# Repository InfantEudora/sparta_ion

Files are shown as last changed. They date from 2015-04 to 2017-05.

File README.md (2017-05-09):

Open Source Sparta ION
=============
There's a bunch of (Dutch) blog posts that go with this: (http://infant.tweakblogs.net/blog/cat/2875)

This repository contains the following:

 folder       |  descr
--------------|-------------------------------------------------------------
 eagle        | All relevant eagle files, BOM lists.
 ion_firmware | AVR Studio projects for the different kinds of firmware.
 ion_software | Software for testing, or uploading hex files.
 lib          | Files used in either firmware or software.
 lib_ion      | Files used for Sparta ION specific code.

All files in this repository are released under GNU GPLv3 (https://www.gnu.org/copyleft/gpl.html)

Software used:
----------------
 - Atmel Studio 6.1.2440 - BETA (http://www.atmel.com/microsite/atmel_studio6/)
 - GCC 4.9.2
 - Windows: Cygwin(https://cygwin.com/install.html)
 - Eagle 6.1.0 (http://www.cadsoftusa.com/)

Firmware:
----------------

The firmware running your bike's motor, consists of three parts:
 - A bootloader, started on powerup.
 - The actual firmware, called application executed by the bootloader.
 - Configuration memory, stored in ROM.

The bootloader uses two blocks to identify the harware it's running on, and what firmware should be loaded.
The firware uses one block to read/write settings, which are currently the strain gauge calibration.

If you wan't to build a control PCB, use the latest revision of 3phasecntrl.

New Hardare Revision Wishlist:
 - Crystal
 - ESD protection on HALL input. (REV2)

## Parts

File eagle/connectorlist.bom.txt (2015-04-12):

CONNECTOR LIST:

Display:
TE CONNECTIVITY / AMP  1445022-3 HOUSING, RECEPTACLE, SINGLE ROW, 3WAY
1111082

TE CONNECTIVITY / AMP  794610-1  CONTACT SOCKET, 24-20AWG, CRIMP
1111151

TE CONNECTIVITY / AMP  0-1445049-3  CONNECTOR HOUSING, PLUG, 3 WAY, NYLON
1111098

TE CONNECTIVITY / AMP  1-794612-0  CONTACT PIN, 20-24AWG
1111149

Motor:
TE CONNECTIVITY / AMP  282105-1  TAB HOUSING, 3WAY
150678

TE CONNECTIVITY / AMP  282087-1  SOCKET HOUSING, 3WAY
150423

TE CONNECTIVITY / AMP  183025-1.  CRIMP SOCKET, 18-15AWG
151075

TE CONNECTIVITY / AMP  183024-1  CRIMP PIN, TAB, 20-15AWG
151040

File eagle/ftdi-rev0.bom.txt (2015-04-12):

Partlist exported from E:/IDE-E/Mijn Documenten/Projects/code/sparta_ion.git/eagle/ftdi.sch at 4/8/2015 5:38:11 PM

Assembly variant: 

Qty Value        Device            Parts             Farnell FarnellAlt1
1                ADAFRUIT_USBMINIB USB                                  
2                JP1E              XIN, XOUT                            
2                MA03-1            X1, X2                               
2                MA04-1            SV1, SV2                             
1                SJ                SJ1                                  
1                SJ2W              SJ2                                  
4   1k           R-EU_M0805        R3, R30, R32, R35 2078954            
1   2R2          R-EU_M0805        F1                2078937            
1   4.7u/16V     C-EUC0805K        C1                1759427            
1   4k7          R-EU_M0805        R2                2074469            
2   10R          R-EU_M0805        R31, R36          2073604            
1   100k         R-EU_M0805        R34               2073608            
3   100n         C-EUC0805K        C2, C3, C45       2320839            
1   390k         R-EU_M0805        R33               9234322            
3   470R         R-EU_M0805        R1, R8, R67       2073777            
3   BC847        BC847             T1, T5, T6        1081232            
1   EL3H7(TA)-VG TLP283            OK1                                  
1   FT232RL      FT232RL           IC1               1146032            
1   GREEN        LEDCHIPLED_0805   TX                2290331            
1   RED          LEDCHIPLED_0805   RX                1318244            
1   SN65HVD1780  SN75176BD         U1

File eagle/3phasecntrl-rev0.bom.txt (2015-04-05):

Partlist exported from E:/IDE-E/Mijn Documenten/Projects/code/sparta_ion.git/eagle/3phasecntrl-rev0.sch at 4/5/2015 2:22:53 PM

Assembly variant: 

Qty Value              Device             Parts                              Farnell FarnellAlt1
1                      MA03-1             STRAIN                                                
1                      MA05-1             X3-HALL                                               
2                      MA07-1             MMUP, PWM                          1516283            
1                      SJ2W               VBUS                                                  
7   1k                 R-EU_M0805         R10, R12, R30, R35, R45, R67, R68  2078954            
1   2R2                R-EU_M0805         R58                                2078937            
1   4.7u/16V           C-EUC0805K         C16                                1759427            
4   4k7                R-EU_M0805         R8, R13, R14, R32                  2074469            
8   10R                R-EU_M0805         R3, R4, R5, R6, R7, R9, R11, R31   2073604            
2   10u/16V            CPOL-EU153CLV-0405 C4, C11                            9265554 9696920    
1   10u/50V            CPOL-EU153CLV-0605 C6                                 2068686            
1   68u/25V            CPOL-EU153CLV-0605 C5                                 2326209            
3   100k               R-EU_M0805         R1, R27, R34                       2073608            
8   100n               C-EUC0805K         C1, C2, C3, C7, C14, C15, C19, C20 2320839            
1   140mA              PTCFUSE-1812       F1                                 1345923            
1   150u/250mA         L-USWE-TPC         L1                                 2328764            
1   240k               R-EU_M0805         R29                                2139055            
3   390k               R-EU_M0805         R26, R28, R33                      9234322            
4   470R               R-EU_M0805         R2, R18, R21, R22                  2073777            
1   ATXmega32A4U       XMEGA16A4A         IC3                                2443192            
1   BAT46WH            DIODE-SOD323-W     D5                                 2069340            
2   BC847              BC847              T1, T2                             1081232            
1   GREEN              LEDCHIPLED_0805    LED1                               2290331            
1   LD1117S33          LM340ST-ST         IC6                                1467779            
1   LD1117S50          LM340ST-ST         IC4                                1467780            
1   LM5008MM           LM5008MM           U1                                 2112610            
3   MOUNT-PAD-ROUND3.2 MOUNT-PAD-ROUND3.2 H1, H2, H3                                            
1   PROG-ATMEL-PDI     PROG-ATMEL-PDI     XP                                                    
1   RED                LEDCHIPLED_0805    LED2                               1318244            
1   SM6T39A            DIODE-SMB          D4                                 9802703            
1   SS110B             DIODE-SMB          D1                                 1861422

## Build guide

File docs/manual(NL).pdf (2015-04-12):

## Aansluiten:

(REV0 en REV1)

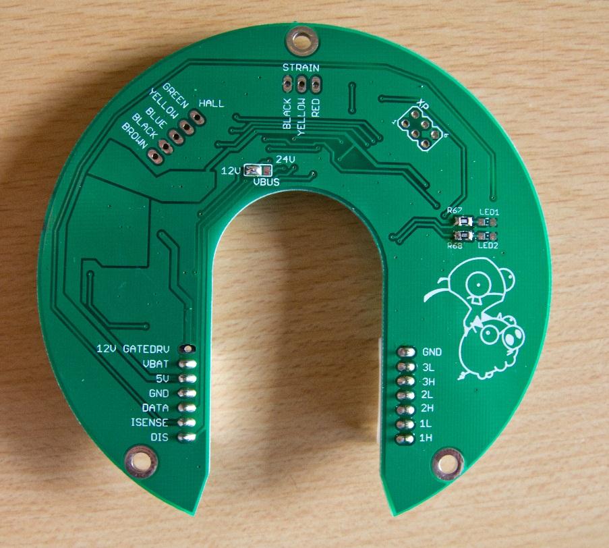
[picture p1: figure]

De vervanging voor het originele Sparta control PCB, kan los getest worden, zonder dat hij eerst ingebouwd hoeft te worden en het is ook niet nodig hem op de drive PCB aan te sluiten.

De GND en VBAT aansluiting op de linker connector hierboven. Het PCB heeft 6.5V nodig om op te starten, en in het geval van een 12V bus zoals hierboven, 10V om goed met het display te communiceren. Het hele PCB is ompool beveiligd. (De drive PCB echter niet.)

Nadat het PCB aan staat, gaat heel even het rode led alleen aan. Hier bevind het PCB zich in bootload mode. Binnen 1 seconde wordt de firmware uitgevoerd, en gaat het groene led knipperen.

Als het display niet aangesloten is, licht het rode led op, het groene led blijft door knipperen. Zodra het display aangesloten is, knippert alleen het groene led nog.

Het display heeft 5V nodig, de GND is aan de batterij min gekoppeld. De 5V mag van dit PCB komen, of een externe.

De connector uit het ronde display heeft een wit, geel en rood of oranje draad:

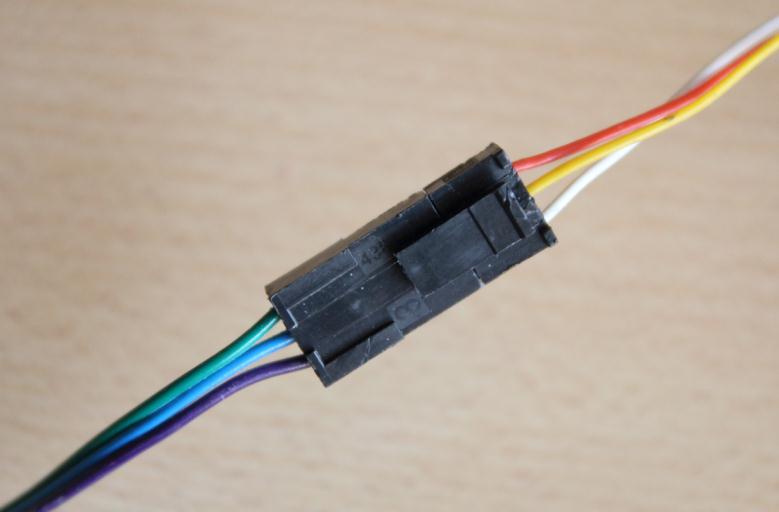
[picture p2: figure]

De male connector die oorspronkelijk uit de accu komt kan gebruikt worden, de kleur codering staat ook in het eagle schema:

Display Connector (Female) | Accu Connector (Male) | Signaal
Rood | Groen | 5V
Geel | Blauw | DATA
Wit | Paars | GND

Als je de display draad door de as naar buiten wilt brengen, is het handig om die op de linker connector punten te solderen.

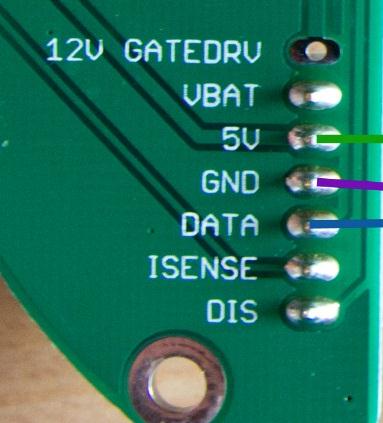
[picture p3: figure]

Bij het losmaken van het orgineel is het handig eerst de hall sensor draden los te solderen, vervolgens het PCB lost schroeven en de twee connectoren los maken. Als laatste te trapas sensor draden los maken.

Let bij het terugzetten er weer op dat de trapas sensor vanaf de onderzijde van het PCB gaat, en de hall sensoren via de bovenkant:

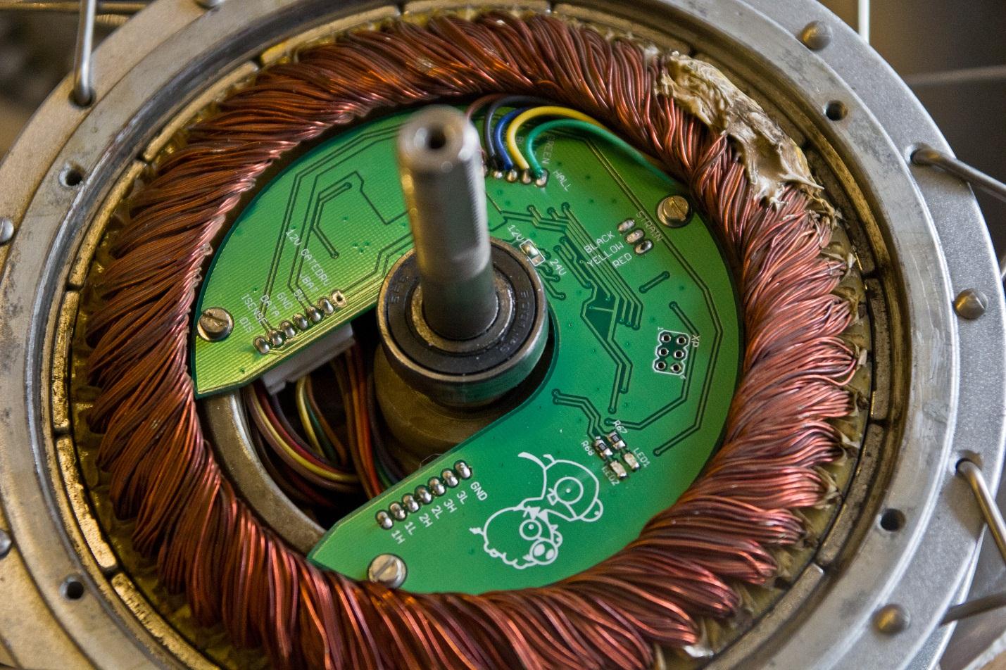
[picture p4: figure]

De connector die oorspronkelijk uit de accu naar de motor loopt, wordt geschakeld: de plus van de accu zit niet permanent aan de motor verbonden.

Het is op het moment nodig, en gezien de kans groot is dat jouw accu PCB niet meer werkt, de accu plus en min direct op de motor te zetten:

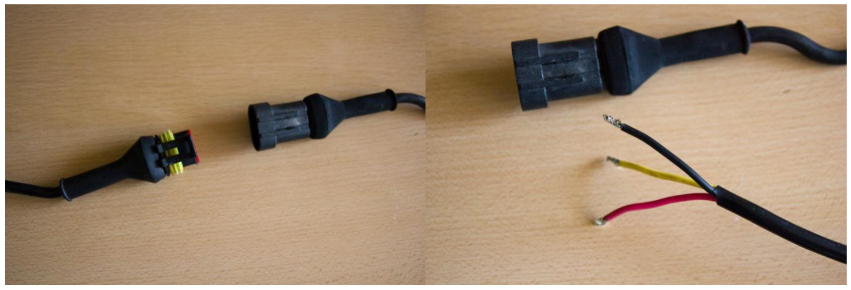
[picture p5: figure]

De kleurcodering hier is:

Accu Min | Zwart
Data | Geel
Accu Plus | Rood
Er is geen enkele reden dat de data draad zo dik moet zijn. Er gaat hoogstens een paar mA door heen.

De spannings-rating van de componenten die aan de accu hangen zijn 50V. Dit control PCB heeft een ingangs TVS diode die c.a. 39V gaat geleiden. De overspanning staat in de firmware rond de 38V, als deze spanning gemeten wordt, slaat de trapondersteuning af.

De onderspanning zit op 18V. Rond de 19V wordt het vermogen terug geregeld.

Normaliter is de accu rond de 28V als hij vol is, en 20V als hij leeg is.

## Display:

Op het moment van schrijven zijn een aantal van de originele features weg:
- Accu percentage. (Gezien dit toch gegarandeerd een keer de mist in gaat.)
- Afgelegde afstand.
- Aansturen van verlichting. (Dit zit in de accu, maar dient via het display aangezet te worden.)

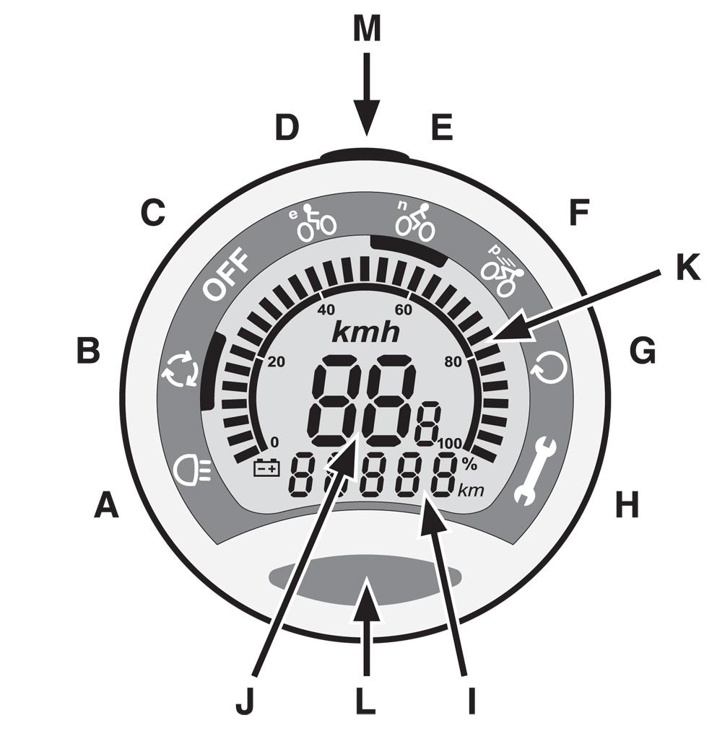
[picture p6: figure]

In normale toestand toont het scherm de snelheid op [J]. De stroom uit de accu (positief of negatief bij terug leveren) op [I]. [K] geeft het throttle signaal of trapkracht aan, van 0-100. De hoogste van de twee wordt getoond.

Met de middelste knop gaat de trapondersteuning aan, er zijn 5 standen. Elke stand regelt naar 3 Ampere * percentage throttle. Als het wiel van de grond is, betekend dit dat in elke stand met elke hoeveelheid throttle uiteindelijk het wiel op maximum snelheid gaat draaien.

De bovenste knop ingedrukt houden, en daarna de middelste schakelt de display verlichting aan/uit.

De bovenste knop (M) navigeert nu door verschillende menu’s heen, met de knop aan de voorkant selecteer je opties en stel je waardes in.

Menu F1:

- 0: [J] toont snelheid.
- 1: [J] toont accu spanning.
- 2: [J] toont trapsensor waarde. (Rond de 500).
- 3: Minimum trapsensor waarde.
- 4: Maximum trapsensor waarde.
- 5: 6-fase PWM waarde.

Menu F2:

Stelt de PWM limiet in. Standaard staat deze op 9. Dit beïnvloed de topsnelheid, maar ook de maximum kracht. Op stand 0 zul je merken dat hij vrijwel altijd tegen werkt, en er stroom de accu in loopt.

Menu F3:

Calibratie voor trapas sensor. De middelste knop ingedrukt houden gaat de waarde mee omhoog zolang het hudige signaal op de sensor grooter is dan de calibratie waarde. Als je de bovenste knop langer dan c.a. 5 sec. ingedrukt houd, reset de waarde en kom je in menu F3 terecht.

Menu F4:

Als deze op waarde 4 gezet wordt, en je gaat terug naar het hoofdscherm kun je gas geven met de middelste knop. Dit is handig om te testen.

Menu F5:

Schaal factor voor de trapas sensor, een hoger getal betekend dat je minder kracht hoeft te zetten voordat hij gaat helpen.

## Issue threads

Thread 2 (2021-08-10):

Communication with original Motor PCB

stancecoke, 2021-08-10:
Hi, I've sniffed the communication from an original Sparta ION system and get the a very similar data stream, like you reported here:
http://nattesok.nl/tweakers/banaan/485-18V(D-)-DATA(D+)-chopped%20-%20accu1%20-%20session%201%20-%20motor.log

In your bowbus.c, there is a request from the battery to the motor to get the motor state.
https://github.com/InfantEudora/sparta_ion/blob/a58da4fbbf7ff044e3546b9d482d39e81046c3de/lib_ion/bowbus.c#L463

Is this command specific for your self made Motor PCB, or does it work with the original Motor PCB also?

regards
stancecoke

InfantEudora, 2021-08-10:
Unfortunately, I've never actually had a working original one. It was mostly the motor that was broken.
So as you say, the `bus_motor_poll `polls the self made pcb. It replies in `bus_send_battery_ack`.

I do believe the original motor uses the same address, but there might be more going on.

stancecoke, 2021-08-10:
OK, thank you. I'll log more data during riding and try to analyze them....

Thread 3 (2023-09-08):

Re-publish blog posts

dirkpostma, 2023-09-08:
The link to blogpost doesn’t work anymore as Tweakers stopped hosting tweakblogs. Is it possible that you publish your articles somewhere else? Would be awesome!

Arjan-Karman, 2023-09-08:
I'm not the original poster of the blog, but I made some sort of a backup PDF of the tweakblog posts about the sparta ion when I was trying to get this to work.
I think I've still got some PCB's somewhere!

[sparta tweakblog.pdf](https://github.com/InfantEudora/sparta_ion/files/12558704/sparta.tweakblog.pdf)

InfantEudora, 2023-09-08:
Hi. Yeah, it would be. I do have them backed-up. I will need to find the time to go through them.
Thanks for the pdf!

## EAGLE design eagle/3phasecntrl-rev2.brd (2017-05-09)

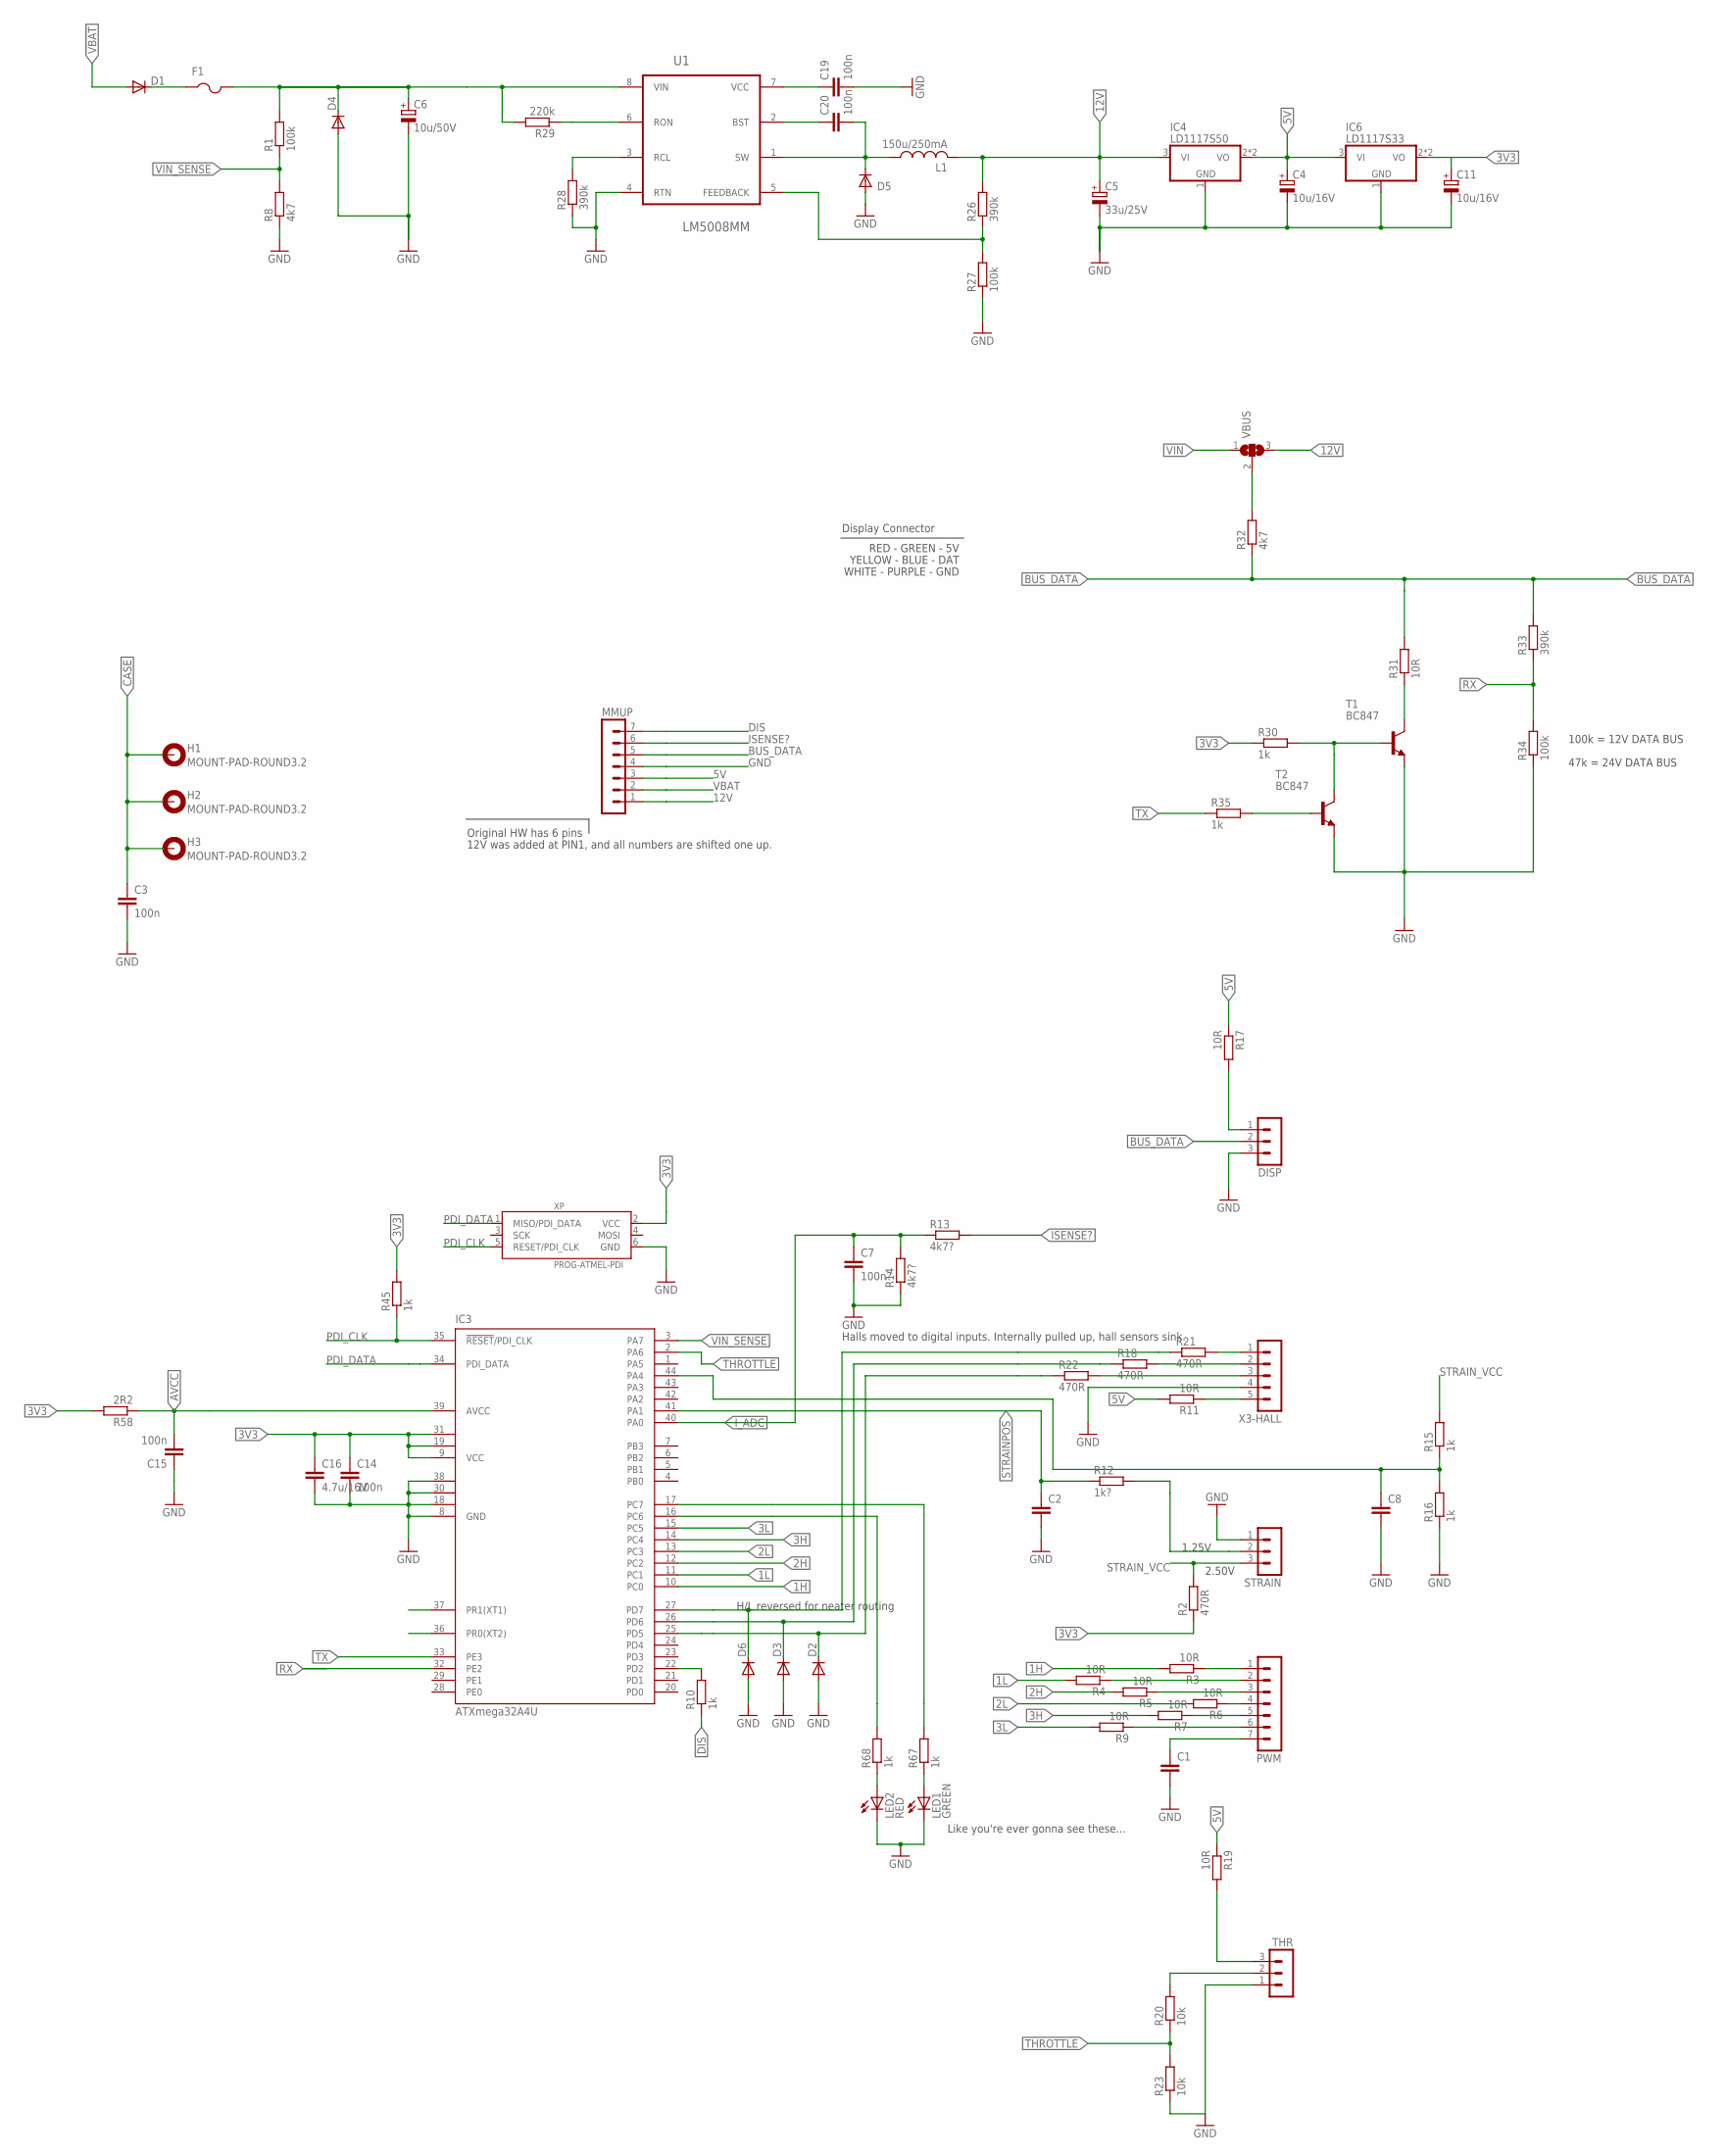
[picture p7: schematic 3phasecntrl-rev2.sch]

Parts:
C1, C2, C8: C-EUC0805K; C0805K
C3, C14, C15, C19, C20: 100n; C0805K
C4, C11: 10u/16V; 153CLV-0405
C5: 33u/25V; 153CLV-0605
C6: 10u/50V; 153CLV-0605
C7: 100n?; C0805K
C16: 4.7u/16V; C0805K
D1: BAT46WH; SMB; FARNELL 2069340
D2, D3, D6: PTVS3V3S1UTR; SOD123; FARNELL 2575110
D4: SM6T39A; SMB; FARNELL 9802703
D5: BAT46WH; SOD323-W
DISP: MA03-1
F1: PTCFUSE-1812; 1812
H1, H2, H3: MOUNT-PAD-ROUND3.2; 3,2-PAD
IC3: ATXmega32A4U; TQFP44
IC4: LD1117S50; SOT223; FARNELL 1467780
IC6: LD1117S33; SOT223
L1: 150u/250mA; POWER-CHOKE_WE-TPC
LED1: GREEN; CHIPLED_0805
LED2: RED; CHIPLED_0805
MMUP: MA07-1
PWM: MA07-1
R1, R27, R34: 100k; M0805
R2, R18, R21, R22: 470R; M0805
R3, R4, R5, R6, R7, R9, R11, R17, R19, R31: 10R; M0805
R8, R32: 4k7; M0805
R10, R15, R16, R30, R35, R67, R68: 1k; M0805
R12: 1k?; M0805
R13, R14: 4k7?; M0805
R20, R23: 10k; M0805
R26, R28, R33: 390k; M0805
R29: 220k; M0805
R45: 1k; R0805
R58: 2R2; R0805
STRAIN: MA03-1
T1, T2: BC847; SOT23
THR: MA03-1
U1: LM5008MM; SOP65P490X109-8N
VBUS: SJ2W; SJ_2
X3-HALL: MA05-1
XP: PROG-ATMEL-PDI; 6-LSTB2

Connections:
1H: IC3.10 (PC0), R3.2
1L: IC3.11 (PC1), R4.2
2H: IC3.12 (PC2), R5.2
2L: IC3.13 (PC3), R6.2
3H: IC3.14 (PC4), R7.2
3L: IC3.15 (PC5), R9.2
3V3: C11.+, C14.1, C16.1, IC3.9 (VCC), IC3.19 (VCC1), IC3.31 (VCC2), IC6.2 (VO), IC6.4 (VO), R2.1, R30.1, R45.2, R58.2, XP.2 (VCC)
5V: C4.+, IC4.2 (VO), IC4.4 (VO), IC6.3 (VI), MMUP.3, R11.2, R17.1, R19.1
12V: C5.+, IC4.3 (VI), L1.2, MMUP.1, R26.2, VBUS.3
AVCC: C15.2, IC3.39 (AVCC), R58.1
BUS_DATA: DISP.2, MMUP.5, R31.2, R32.1, R33.2
CASE: C3.1, H1.B3,2, H2.B3,2, H3.B3,2
DIS: MMUP.7, R10.1
GND: C1.2, C2.2, C3.2, C4.-, C5.-, C6.-, C7.2, C8.2, C11.-, C14.2, C15.1, C16.2, C19.2, D2.A, D3.A, D4.A, D5.A, D6.A, DISP.3, IC3.8 (GND), IC3.18 (GND1), IC3.30 (GND2), IC3.38 (GND3), IC4.1 (GND), IC6.1 (GND), LED1.C, LED2.C, MMUP.4, R8.1, R14.1, R16.1, R23.1, R27.1, R28.1, R34.1, STRAIN.1, T1.2 (E), T2.2 (E), THR.1, U1.4 (RTN), X3-HALL.4, XP.6 (GND)
ISENSE?: MMUP.6, R13.2
I_ADC: C7.1, IC3.40 (PA0), R13.1, R14.2
unnamed: C1.1, PWM.7
unnamed: D1.C, F1.1
unnamed: C19.1, U1.7 (VCC)
unnamed: PWM.1, R3.1
unnamed: R12.2, STRAIN.2
unnamed: R32.2, VBUS.2
unnamed: IC3.22 (PD2), R10.2
unnamed: R11.1, X3-HALL.5
unnamed: R21.2, X3-HALL.1
unnamed: PWM.2, R4.1
unnamed: R18.2, X3-HALL.2
unnamed: R31.1, T1.3 (C)
unnamed: R22.2, X3-HALL.3
unnamed: LED1.A, R67.1
unnamed: LED2.A, R68.1
unnamed: C20.1, U1.2 (BST)
unnamed: R19.2, THR.3
unnamed: D6.C, IC3.27 (PD7), R21.1
unnamed: IC3.16 (PC6), R68.2
unnamed: IC3.17 (PC7), R67.2
unnamed: C20.2, D5.C, L1.1, U1.1 (SW)
unnamed: R35.2, T2.1 (B)
unnamed: R26.1, R27.2, U1.5 (FEEDBACK)
unnamed: R30.2, T1.1 (B), T2.3 (C)
unnamed: D3.C, IC3.26 (PD6), R18.1
unnamed: R28.2, U1.3 (RCL)
unnamed: PWM.3, R5.1
unnamed: PWM.4, R6.1
unnamed: R29.1, U1.6 (RON)
unnamed: D2.C, IC3.25 (PD5), R22.1
unnamed: PWM.5, R7.1
unnamed: PWM.6, R9.1
unnamed: DISP.1, R17.2
PDI_CLK: IC3.35 (!RESET!/PDI_CLK), R45.1, XP.5 (RESET/PDI_CLK)
PDI_DATA: IC3.34 (PDI_DATA), XP.1 (MISO/PDI_DATA)
RX: IC3.32 (PE2), R33.1, R34.2
STRAINPOS: C2.1, IC3.41 (PA1), R12.1
STRAINREF: C8.1, IC3.44 (PA4), R15.1, R16.2
STRAIN_VCC: R2.2, R15.2, STRAIN.3
THIN: R20.2, THR.2
THROTTLE: IC3.2 (PA6), R20.1, R23.2
TX: IC3.33 (PE3), R35.1
VBAT: D1.A, MMUP.2
VIN: C6.+, D4.C, F1.2, R1.2, R29.2, U1.8 (VIN), VBUS.1
VIN_SENSE: IC3.3 (PA7), R1.1, R8.2

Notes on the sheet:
RED - GREEN - 5V
WHITE - PURPLE - GND
YELLOW - BLUE - DAT
1.25V
2.50V
Original HW has 6 pins
12V was added at PIN1, and all numbers are shifted one up.
Display Connector
H/L reversed for neater routing
Like you're ever gonna see these...
Halls moved to digital inputs. Internally pulled up, hall sensors sink.
100k = 12V DATA BUS
47k = 24V DATA BUS

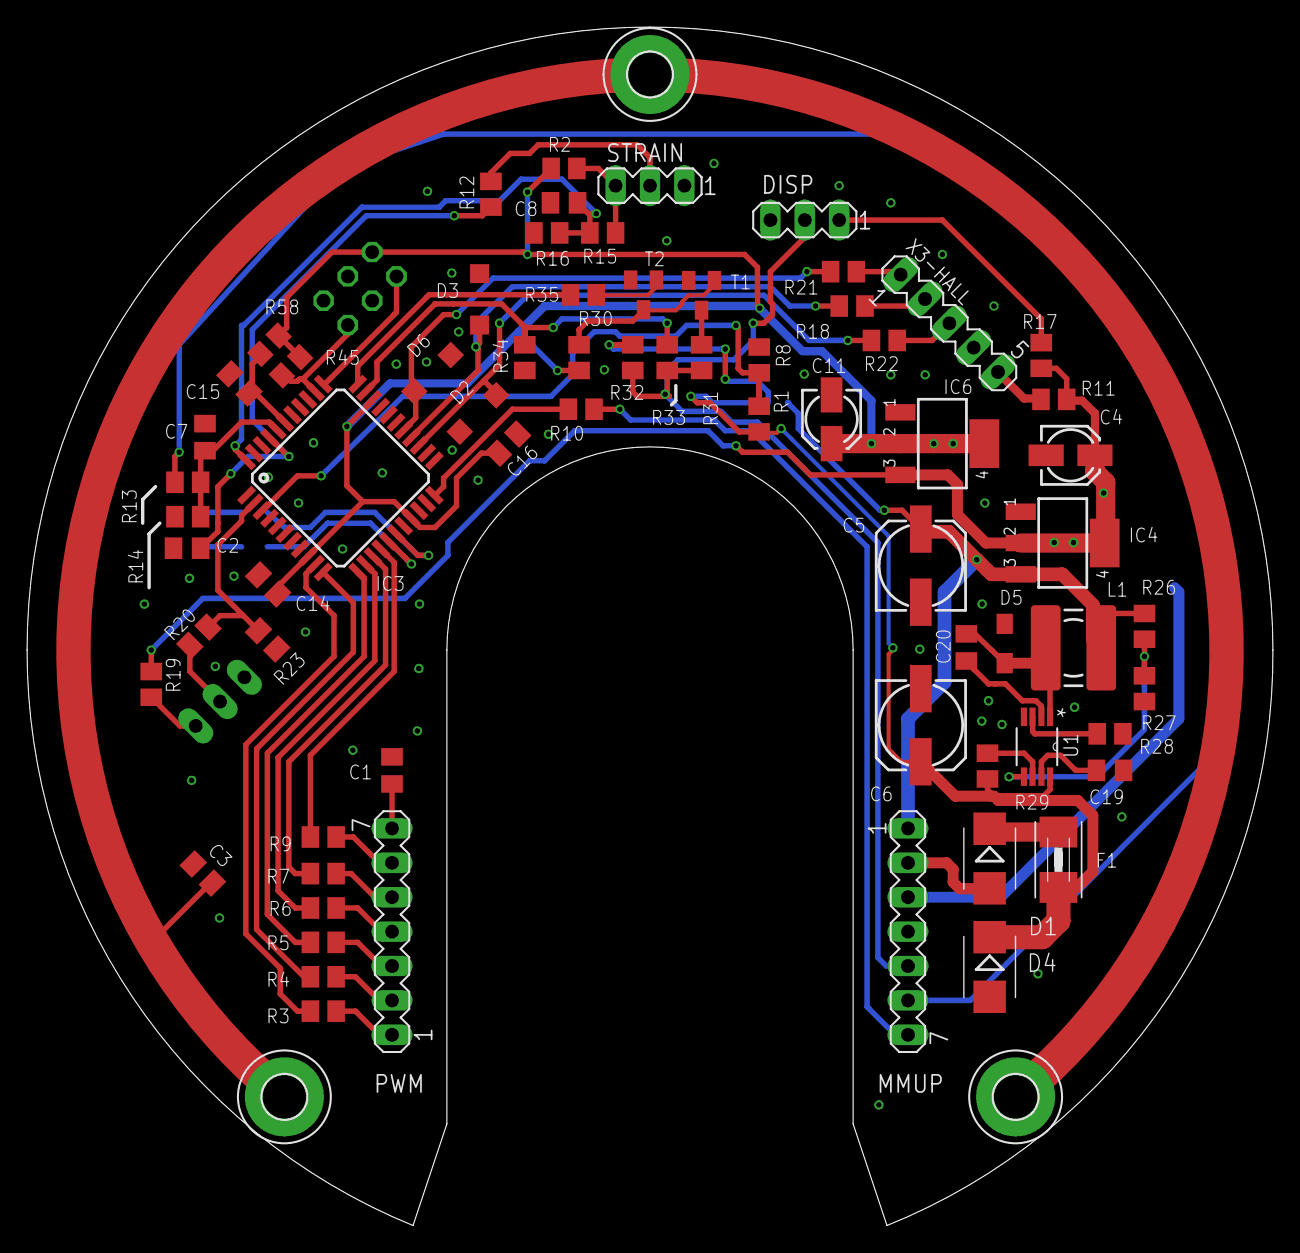
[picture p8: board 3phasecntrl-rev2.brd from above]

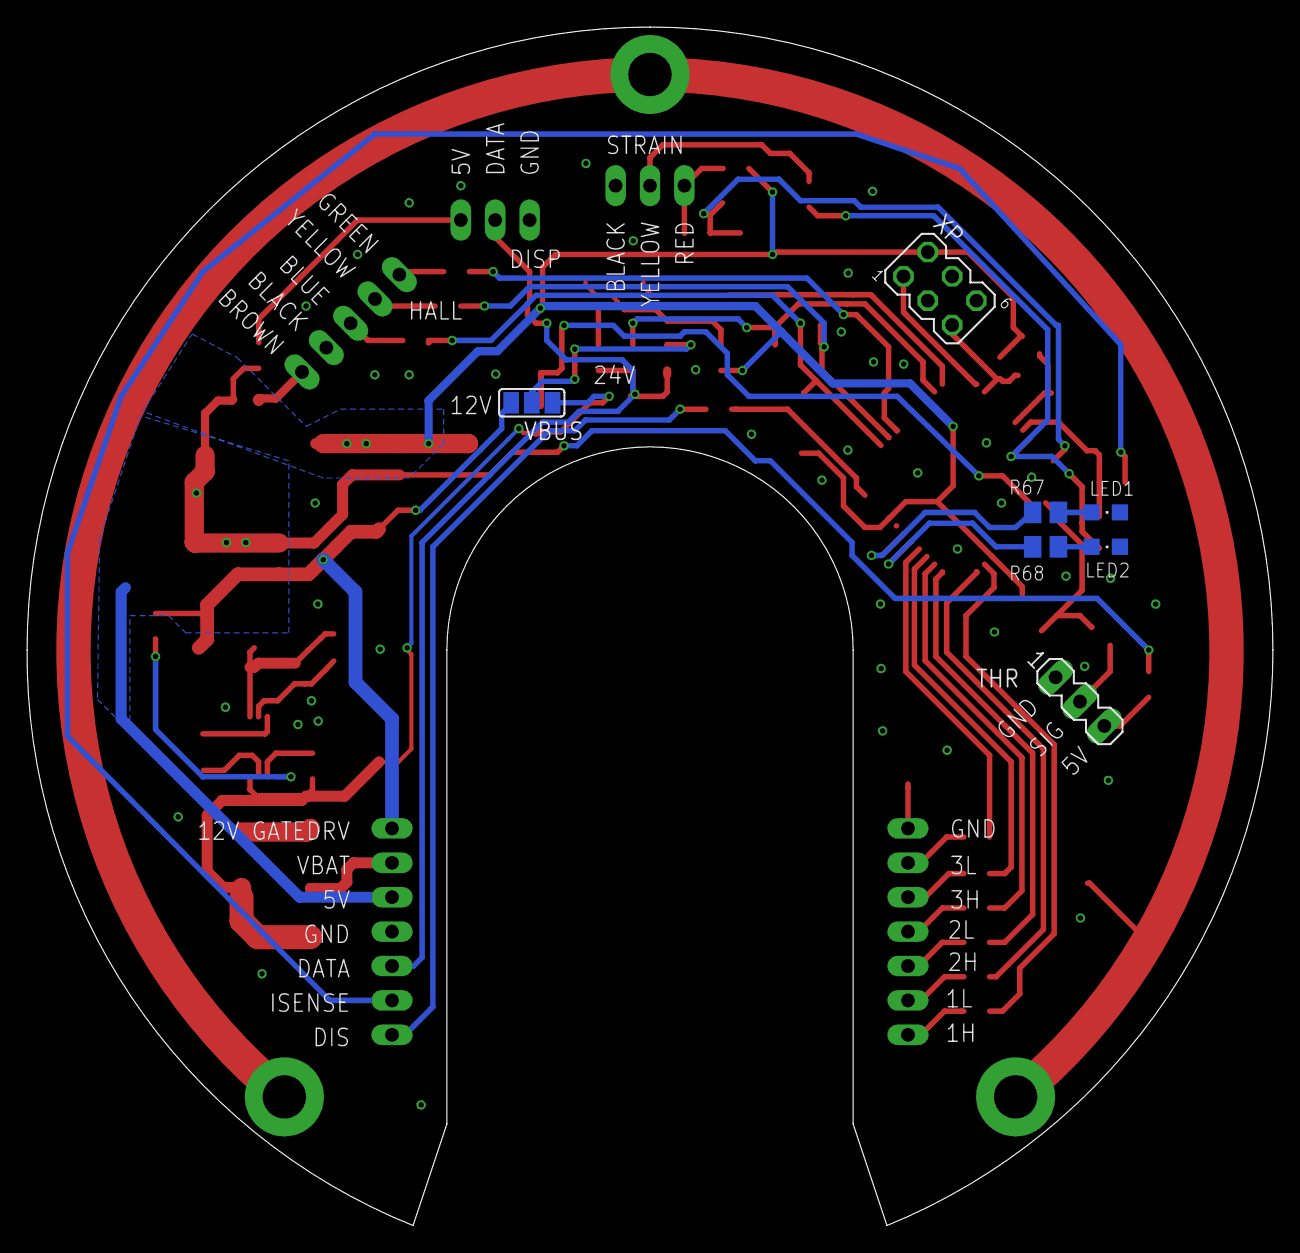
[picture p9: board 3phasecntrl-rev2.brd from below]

Board: 2 copper layers, 92.0 x 88.5 mm, 78 parts (7 on the bottom side), 61 nets.

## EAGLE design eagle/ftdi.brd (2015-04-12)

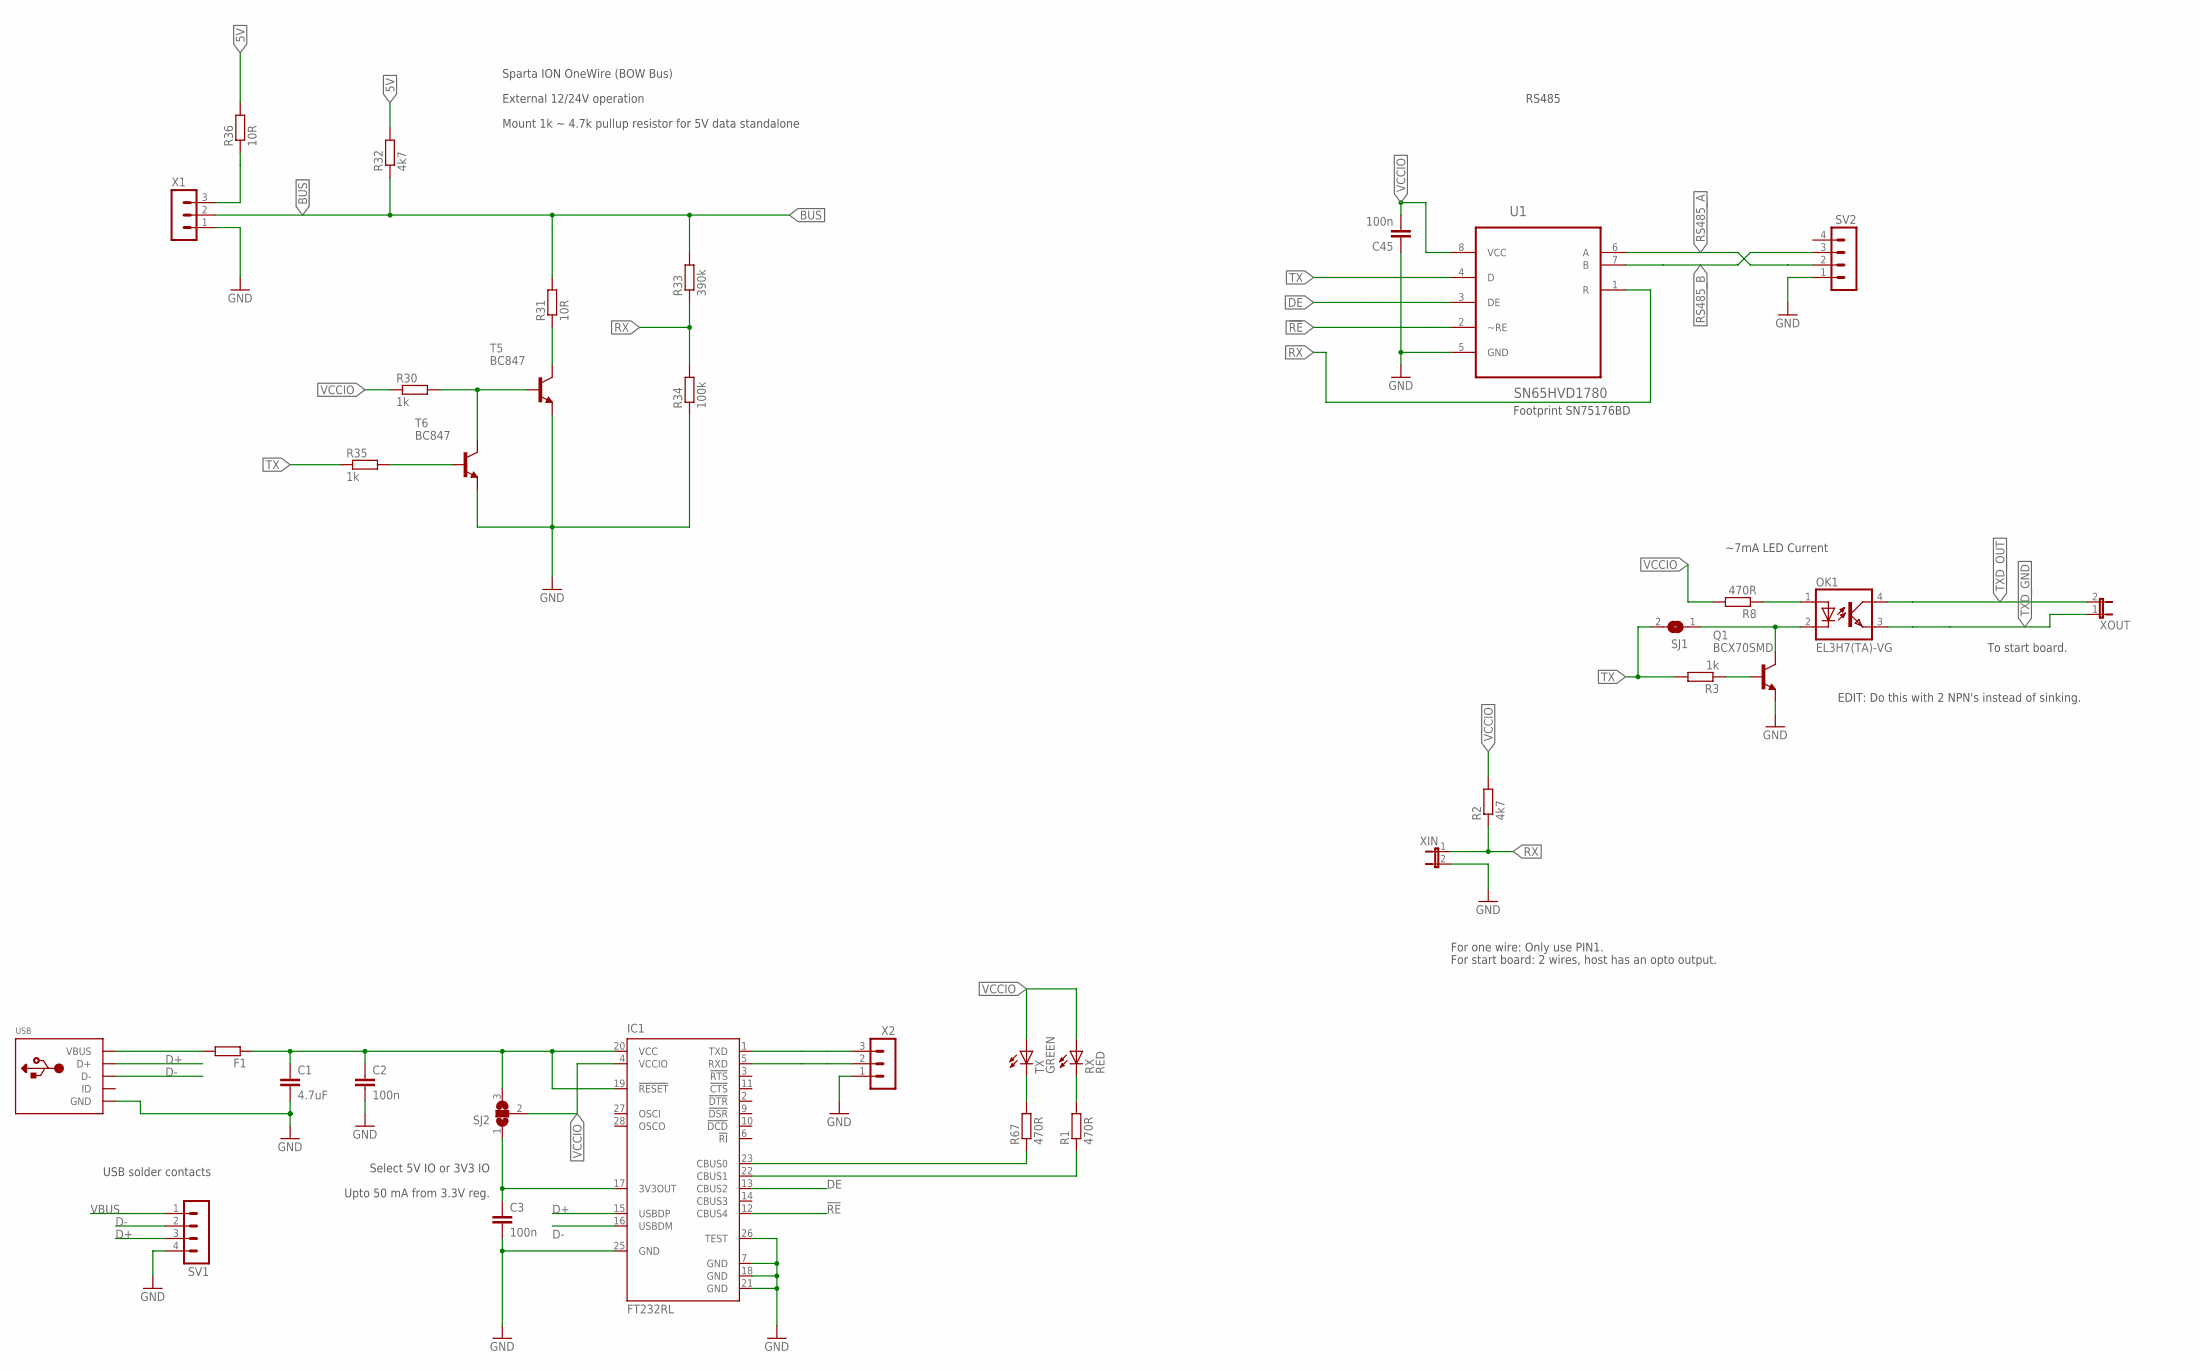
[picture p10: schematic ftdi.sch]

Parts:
C1: 4.7uF; C0805
C2, C3, C45: 100n; C0805
F1: R-EU_R0805; R0805
IC1: FT232RL; SSOP28
OK1: EL3H7(TA)-VG; MINI-FLAT-4
Q1: BCX70SMD; SOT23
R1, R67: 470R; M0805
R2: 4k7; R0805
R3: 1k; R0805
R8: 470R; R0805
R30, R35: 1k; M0805
R31, R36: 10R; M0805
R32: 4k7; M0805
R33: 390k; M0805
R34: 100k; M0805
RX: RED; CHIPLED_0805
SJ1: SJ
SJ2: SJ2W; SJ_2
SV1, SV2: MA04-1
T5, T6: BC847; SOT23
TX: GREEN; CHIPLED_0805
U1: SN65HVD1780; SOIC127P600X175-8N
USB: ADAFRUIT_USBMINIB; ADAFRUIT_USB-MINIB
X1, X2: MA03-1
XIN: JP1E; JP1
XOUT: JP1E; JP1

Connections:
5V: C1.1, C2.1, F1.1, IC1.19 (!RESET), IC1.20 (VCC), R32.2, R36.2, SJ2.3
!RE: IC1.12 (CBUS4), U1.2 (~RE)
BUS: R31.2, R32.1, R33.2, X1.2
D+: IC1.15 (USBDP), SV1.3, USB.D+
D-: IC1.16 (USBDM), SV1.2, USB.D-
DE: IC1.13 (CBUS2), U1.3 (DE)
GND: C1.2, C2.2, C3.2, C45.1, IC1.7 (GND), IC1.18 (GND), IC1.21 (GND), IC1.25 (GND), IC1.26 (TEST), Q1.2 (E), R34.1, SV1.4, SV2.1, T5.2 (E), T6.2 (E), U1.5 (GND), USB.GND, X1.1, X2.1, XIN.2
GND1: IC1.23 (CBUS0), R67.1
GND2: IC1.22 (CBUS1), R1.1
unnamed: C3.1, IC1.17 (3V3OUT), SJ2.1
unnamed: R1.2, RX.C
unnamed: OK1.2 (C), Q1.3 (C), SJ1.1
unnamed: OK1.1 (A), R8.1
unnamed: Q1.1 (B), R3.1
unnamed: R31.1, T5.3 (C)
unnamed: R35.2, T6.1 (B)
unnamed: R30.2, T5.1 (B), T6.3 (C)
unnamed: R36.1, X1.3
unnamed: R67.2, TX.C
RS485_A: SV2.2, U1.6 (A)
RS485_B: SV2.3, U1.7 (B)
RX: IC1.5 (RXD), R2.1, R33.1, R34.2, U1.1 (R), X2.2, XIN.1
TX: IC1.1 (TXD), R3.2, R35.1, SJ1.2, U1.4 (D), X2.3
TXD_GND: OK1.3 (EMIT), XOUT.1
TXD_OUT: OK1.4 (COL), XOUT.2
VBUS: F1.2, SV1.1, USB.VBUS
VCCIO: C45.2, IC1.4 (VCCIO), R2.2, R8.2, R30.1, RX.A, SJ2.2, TX.A, U1.8 (VCC)

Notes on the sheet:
Upto 50 mA from 3.3V reg.
Sparta ION OneWire (BOW Bus)
External 12/24V operation
Footprint SN75176BD
RS485
USB solder contacts
~7mA LED Current
To start board.
For one wire: Only use PIN1.
For start board: 2 wires, host has an opto output.
Mount 1k ~ 4.7k pullup resistor for 5V data standalone
Select 5V IO or 3V3 IO
EDIT: Do this with 2 NPN's instead of sinking.

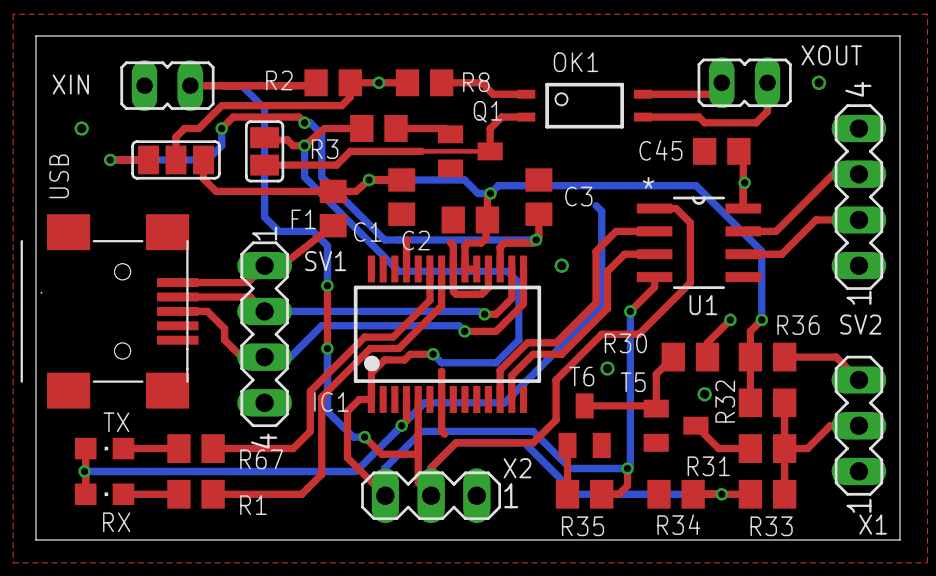
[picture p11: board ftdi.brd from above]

Board: 2 copper layers, 48.0 x 28.0 mm, 34 parts (0 on the bottom side), 27 nets.

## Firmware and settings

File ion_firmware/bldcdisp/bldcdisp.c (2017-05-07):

/*
	Created: 2014-06-23T17:07:46Z
	Author: D. Prins
		Infant - infant.tweakblogs.net
		mail: prinsje2004 at gmail

		File: bldcdisp.c
	Application running on Sparta ION Control Board.
	Responsible for generating motor drive signals and display communication.
	Features and hardware definitions are set/defined in app.h

	This code is released under GNU GPL v3:

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
	    You should have received a copy of the GNU General Public License
    along with this program.  If not, see <http://www.gnu.org/licenses/>.
*/

#define F_CPU 32000000UL
#include <util/delay.h>

#include <avr/io.h>
#include <stdio.h>
#include <stdint.h>
#include <stdbool.h>

#include <avr/interrupt.h>
#include "app.h"
#include "adc.h"
#include "uart.h"
#include "../fwcommon/eeprom.h"
#include "../../lib_ion/bowbus.h"


#define REF_1V0				ADC_REFSEL_INT1V_gc
//Some version of AVR studio may complain here, and wants this set to ADC_REFSEL_VCC_gc
#define REF_3V3				ADC_REFSEL_INTVCC_gc

//Absolute PWM limits.
#define PWM_MAX				420
#define PWM_SET_MAX			PWM_MAX - 15
#define PWM_MIN				35
#define PWM_SET_MIN			PWM_MIN //PWM_MIN+3

//Dynamic PWM limits.
volatile uint16_t pwm_set_min = PWM_SET_MIN;
volatile uint16_t pwm_set_max = PWM_SET_MAX;

bool flagsave = false;			//Set when settings need to be saved
settings_t eepsettings;			//The settings.

bool usehall = true;
bool use_throttle = true;		//Apply throttle.
bool use_pedalassist = true;		//Apply throttle.

bool use_brake = false;			//Apply brake
bool flag_keep_pwm = false;

bool flag_brake_lowrpm = false;	//Brake has turned lower mosfets on.

volatile uint8_t brake				= 0;	//0 = no regen, 100 = max regen.
volatile uint8_t throttle_prev		= 0;
volatile uint8_t throttle			= 0;
volatile uint8_t throttle_override  = 0;	//Override for testing.
volatile uint8_t pedal_signal_prev	= 0;
volatile uint8_t pedal_signal		= 0;
volatile uint8_t brake_level		= 0;	//Brake power

//Bitfields for status flags
#define STAT_OK					0x0000
#define STAT_THROTTLE_FAULT		0x0001
#define STAT_OVER_VOLTAGE		0x0002
#define STAT_UNDER_VOLTAGE		0x0004
#define STAT_REGEN_HIGH			0x0008
#define STAT_STOPPED			0x0010
#define STAT_USETHROTTLE		0x0020
#define STAT_HALL_FAULT			0x0040
#define STAT_BRAKE_FAULT		0x0080

//All the possible errors
#define STAT_ERROR_MASK			(STAT_THROTTLE_FAULT | STAT_BRAKE_FAULT | STAT_OVER_VOLTAGE | STAT_UNDER_VOLTAGE | STAT_REGEN_HIGH | STAT_STOPPED )

//Status bitmap
uint32_t status = 0;

//Functions:
void status_set(uint32_t);
void status_clear(void);
bool isfaultset(void);
void pwm_less(uint8_t by);
void pwm_more(uint8_t by);
void pwm_update(void);
void commute_start(void);
void commute_forward(void);
void commute_backward(void);

bool get_throttle(void);
bool get_brake(void);

//For Bowbus
bool bus_check_for_message(void);

uint16_t cnt_2 = 0;
uint8_t led_off_cnt = 0;
uint8_t flag_timer = 0;

#define HALL_MASK (PIN4_bm | PIN5_bm | PIN6_bm)

//Hall peaks
uint16_t hallhi = 0;
uint16_t halllo = 0;

uint8_t hall_state = 0;
uint8_t hall_prev = 0;
uint8_t flag_hall_changed = 0;

uint16_t pwm = PWM_SET_MAX;
uint16_t pwm_prev = PWM_SET_MAX;

uint8_t off = 0;	//Freewheel on/off.
uint8_t tie = 0;	//Tie low to GND.

uint8_t startup = 10;

//If you want the wheel to go the other way.
#define FORWARD 0
#define BACKWARD 1
uint8_t direction = BACKWARD;		//This is actually forward....

//Calibration value for strain sensor.
uint16_t strain_threshhold = 200;
uint8_t strain_cal_inc = 1;

//Strain sensor values.
int32_t ad_strain = 0;
int32_t ad_strain_sum = 0;
int32_t ad_strain_av = 500;		//Center around 500.

int16_t strain_min = 500;		//Self calibrating...
int16_t strain_max = 500;

uint8_t strain_gain = 2;		//Gain factor in throttle.

//If the strain signal registered, how long it should be on for.
uint16_t strain_cnt = 0;

uint32_t ad_temp_ref = 0;			//Factory reference.
uint32_t ad_temp = 0;
uint32_t ad_temp_sum = 0;
uint32_t ad_temp_av = 0;

uint32_t ad_throttle = 0;
uint32_t ad_brake = 0;

uint32_t ad_voltage = 0;
uint32_t ad_voltage_sum = 0;
uint32_t ad_voltage_av = 0;

int32_t ad_current = 0;
int32_t ad_current_sum = 0;		//Sum of current over meas_cnt time.
int32_t ad_current_av = 0;		//The final average, computed on display update.

int32_t power_av = 0;

uint16_t ad_current_regcnt = 0;
int32_t ad_current_regsum = 0;		//Average computed per commutation
int32_t ad_current_regav = 0;		//The average for the commutation loop.

uint16_t meas_cnt = 0;

int32_t ad_currentmin = 0;
int32_t ad_currentmax = 0;

//Get all analog samples on this board.
uint8_t ad_max_samples = 8;


uint16_t time_prev = 0;
uint16_t time_now = 0;
uint32_t time_comm = 0;

uint32_t time_comm_av = 0;
uint32_t time_comm_av_last = 0;

uint32_t commtime_sum = 0;	//Sum of commutation times.
uint32_t commtime_cnt = 0;	//Number of commutations within that period
uint32_t speed = 0;			//in kmh * 1000. So 10000 = 10.0 kmh

uint16_t cnt_commutations = 0;
uint16_t cnt_rotations = 0;

//Regulaton settings
uint8_t slope_throttle = 1;	//Rate at which PWM may increase for throttle.
uint8_t slope_brake = 10;		//Rate at which PWM may increase for brake.

//Throttle limits.
#define THROTTLE_DISC	100		//Throttle disconnected. //600 safe value
#define THROTTLE_LOW	730		//Lowest
#define THROTTLE_HIGH	2890	//Highest
#define THROTTLE_OVER	3900	//Too high //3100 safe value

uint16_t throttle_tick = 0;
bool throttle_cruise = false;

//Strain min and maximum recorded value.
int16_t highestforce = 0;
int16_t lowestforce = 0;

bowbus_net_s bus;

void init(void){
	PORTD.DIRSET = PIN0_bm;
	PORTC.DIRSET = PIN3_bm | PIN2_bm | PIN1_bm | PIN0_bm;
}

void clock_switch32M(void){
	/*Setup clock to run from Internal 32MHz oscillator.*/
	OSC.CTRL |= OSC_RC32MEN_bm;
	while (!(OSC.STATUS & OSC_RC32MRDY_bm));
	CCP = CCP_IOREG_gc;
	CLK.CTRL = CLK_SCLKSEL_RC32M_gc;
	OSC.CTRL &= (~OSC_RC2MEN_bm);
	PORTCFG.CLKEVOUT = (PORTCFG.CLKEVOUT & (~PORTCFG_CLKOUT_gm)) | PORTCFG_CLKOUT_OFF_gc;	// disable peripheral clock
}

void init_pwm(void){
	//PIN direction:
	PORTC.DIRSET = 0xFF;
	//Setup PWM
	TCC0.CTRLA = TC_CLKSEL_DIV8_gc;
	TCC0.CTRLB = TC_WGMODE_SINGLESLOPE_gc;
	TCC0.PER = PWM_MAX;
	//Default PWM value
	TCC0.CCA = pwm_set_max;
	TCC0.CCB = pwm_set_max;
	TCC0.CCC = pwm_set_max;

	//HiRes extensions
	HIRESC.CTRLA = HIRES_HREN_TC0_gc;

	//Dead time:
#if(HARDWARE_VER == HW_CTRL_REV1)
	//Sparta ION Board has hardware deadtime.
	AWEXC.DTHS = 0;
	AWEXC.DTLS = 0;
#else
	AWEXC.DTHS = 1;
	AWEXC.DTLS = 1;
#endif

	AWEXC.STATUS = AWEX_DTHSBUFV_bm | AWEX_DTLSBUFV_bm | AWEX_FDF_bm;

#if(HARDWARE_VER == HW_CTRL_REV1)
	//This hardware has inverted high side inputs, so we'll invert them again.
	PORTC.PIN0CTRL = PORT_INVEN_bm;
	PORTC.PIN2CTRL = PORT_INVEN_bm;
	PORTC.PIN4CTRL = PORT_INVEN_bm;

	//The Low/High are also switched with respect to first board, it routed nicer.
#endif
}

#if(HARDWARE_VER == HW_CTRL_REV1)

void sector_0(void){
	AWEXC.OUTOVEN =  PIN0_bm | PIN1_bm;
	AWEXC.CTRL =  AWEX_DTICCAEN_bm;
	PORTC.OUTCLR = PIN0_bm | PIN1_bm | PIN2_bm | PIN3_bm |  PIN4_bm;
	PORTC.OUTSET = PIN5_bm;
}

void sector_1(void){
	AWEXC.OUTOVEN = PIN0_bm |  PIN1_bm;
	AWEXC.CTRL =  AWEX_DTICCAEN_bm;
	PORTC.OUTCLR = PIN0_bm | PIN1_bm |  PIN2_bm | PIN4_bm | PIN5_bm;
	PORTC.OUTSET = PIN3_bm;
}

void sector_2(void){
	AWEXC.OUTOVEN =  PIN4_bm| PIN5_bm;
	AWEXC.CTRL =  AWEX_DTICCCEN_bm;
	PORTC.OUTCLR = PIN0_bm | PIN1_bm |  PIN2_bm | PIN4_bm | PIN5_bm;
	PORTC.OUTSET = PIN3_bm;
}

void sector_3(void){
	AWEXC.OUTOVEN =  PIN4_bm| PIN5_bm;
	AWEXC.CTRL =  AWEX_DTICCCEN_bm;
	PORTC.OUTCLR =  PIN0_bm | PIN2_bm | PIN3_bm | PIN4_bm | PIN5_bm;
	PORTC.OUTSET = PIN1_bm;
}

void sector_4(void){
	AWEXC.OUTOVEN =  PIN2_bm | PIN3_bm;
	AWEXC.CTRL =  AWEX_DTICCBEN_bm;
	PORTC.OUTCLR = PIN0_bm | PIN2_bm | PIN3_bm | PIN4_bm | PIN5_bm;
	PORTC.OUTSET = PIN1_bm;
}

void sector_5(void){
	AWEXC.OUTOVEN =  PIN2_bm | PIN3_bm;
	AWEXC.CTRL =  AWEX_DTICCBEN_bm;
	PORTC.OUTCLR = PIN0_bm | PIN1_bm | PIN2_bm | PIN3_bm |  PIN4_bm;
	PORTC.OUTSET = PIN5_bm;
}
#else
void sector_0(void){
	AWEXC.OUTOVEN =  PIN0_bm | PIN1_bm;
	AWEXC.CTRL =  AWEX_DTICCAEN_bm;
	PORTC.OUTCLR = PIN0_bm | PIN1_bm | PIN2_bm | PIN3_bm |  PIN5_bm;
	PORTC.OUTSET = PIN4_bm;
}

void sector_1(void){
	AWEXC.OUTOVEN = PIN0_bm |  PIN1_bm;
	AWEXC.CTRL =  AWEX_DTICCAEN_bm;
	PORTC.OUTCLR = PIN0_bm | PIN1_bm |  PIN3_bm | PIN4_bm | PIN5_bm;
	PORTC.OUTSET = PIN2_bm;
}

void sector_2(void){
	AWEXC.OUTOVEN =  PIN4_bm| PIN5_bm;
	AWEXC.CTRL =  AWEX_DTICCCEN_bm;
	PORTC.OUTCLR = PIN0_bm | PIN1_bm |  PIN3_bm | PIN4_bm | PIN5_bm;
	PORTC.OUTSET = PIN2_bm;
}

void sector_3(void){
	AWEXC.OUTOVEN =  PIN4_bm| PIN5_bm;
	AWEXC.CTRL =  AWEX_DTICCCEN_bm ;
	PORTC.OUTCLR =  PIN1_bm | PIN2_bm | PIN3_bm | PIN4_bm | PIN5_bm;
	PORTC.OUTSET = PIN0_bm;
}

void sector_4(void){
	AWEXC.OUTOVEN =  PIN2_bm | PIN3_bm;
	AWEXC.CTRL =  AWEX_DTICCBEN_bm;
	PORTC.OUTCLR = PIN1_bm | PIN2_bm | PIN3_bm | PIN4_bm | PIN5_bm;
	PORTC.OUTSET = PIN0_bm;
}

void sector_5(void){
	AWEXC.OUTOVEN =  PIN2_bm | PIN3_bm;
	AWEXC.CTRL =  AWEX_DTICCBEN_bm;
	PORTC.OUTCLR = PIN0_bm | PIN1_bm | PIN2_bm | PIN3_bm |  PIN5_bm;
	PORTC.OUTSET = PIN4_bm;
}
#endif

void commute_start(void){
	//Set deadtime, HW specific
#if(HARDWARE_VER == HW_CTRL_REV1)
	AWEXC.DTHS = 0;
	AWEXC.DTLS = 0;
#else
	AWEXC.DTHS = 1;
	AWEXC.DTLS = 1;
#endif
	//Apply.
	AWEXC.STATUS = AWEX_DTHSBUFV_bm | AWEX_DTLSBUFV_bm | AWEX_FDF_bm;

	//Reset highside refresh thingy:
	TCD0.CNT = 0;
}

void switch_sector(uint8_t sect){
	switch(sect){
		case 0:
			sector_0();
			break;
		case 1:
			sector_1();
			break;
		case 2:
			sector_2();
			break;
		case 3:
			sector_3();
			break;
		case 4:
			sector_4();
			break;
		case 5:
			sector_5();
			break;
	}
}

void pwm_freewheel(void){
	PORTC.OUTCLR = PIN5_bm | PIN4_bm | PIN3_bm | PIN2_bm | PIN1_bm | PIN0_bm;
	//Dead time:
	AWEXC.OUTOVEN = 0;
	AWEXC.CTRL = 0;
}

/*
	Connect all lower side MOSFETs, it's like shorting the wires together.
	Better not do this while driving really fast.
*/
void tie_ground(void){
	PORTC.OUTCLR = PIN5_bm | PIN4_bm | PIN3_bm | PIN2_bm | PIN1_bm | PIN0_bm;
	//Dead time:
	AWEXC.OUTOVEN = 0;
	AWEXC.CTRL = 0;

	//Enable lower FETs
	#if(HARDWARE_VER == HW_CTRL_REV1)
		PORTC.OUTSET =  PIN5_bm |  PIN3_bm |  PIN1_bm;
	#else
		PORTC.OUTSET =  PIN4_bm |  PIN2_bm |  PIN0_bm;
	#endif
}

//Estimate the PWM value when freewheeling which would yield close to no current.
uint16_t estimate_pwm_byspeed(){
	int16_t pwm_est = 0;
#if((HARDWARE_VER == HW_BLDC_REV1)||(HARDWARE_VER == HW_BLDC_REV0))
	if (speed > 0){
		pwm_est = pwm_set_max - ((((pwm_set_max) - (pwm_set_min)) / 30) * (speed/10));

		if (pwm_est < pwm_set_min){
			pwm_est = pwm_set_min;
		}
		if (pwm_est > pwm_set_max){
			pwm_est = pwm_set_max;
		}
	}else{
		pwm_est = pwm_set_max;
	}
#else
	//Inverted PWM:
	if (speed > 0){
		pwm_est = pwm_set_min + (((uint16_t)speed*12UL)/10UL);

		if (pwm_est < pwm_set_min){
			pwm_est = pwm_set_min;
		}
		if (pwm_est > pwm_set_max){
			pwm_est = pwm_set_max;
		}
	}else{
		pwm_est = pwm_set_min;
	}
#endif
	return (uint16_t)pwm_est;
}

//Get all analog measurement values.
void get_measurements(void){
	uint32_t usample = 0;
	#if(HARDWARE_VER != HW_CTRL_REV1)
	 uint32_t gsample = 0;
	#else
	 int32_t ssample = 0;
	#endif
	uint32_t bsample = 0;
	int32_t isample = 0;

	//Enable lower FETs
	#if(HARDWARE_VER == HW_CTRL_REV1)
		//This board does not have brake/throttle, but a strain.
		for (uint16_t i=0;i<ad_max_samples;i++){
			adc_init_single_ended(REF_3V3,ADC_CH_MUXPOS_PIN7_gc); //Bat Voltage.
			usample += adc_getsample();
			adc_init_strain(REF_1V0); //Strain Sensor.
			ssample += adc_getsample();
			adc_init_temperature();//Internal temp
			bsample += adc_getsample();
			adc_init_differential(REF_3V3,ADC_CH_MUXPOS_PIN0_gc); //Motor current.
			isample += (int16_t)adc_getsample();
		}
	#else
		//This board has analog inputs for brake and throttle.
		for (uint16_t i=0;i<ad_max_samples;i++){
			adc_init_single_ended(REF_3V3,ADC_CH_MUXPOS_PIN7_gc); //Bat Voltage.
			usample += adc_getsample();
			adc_init_single_ended(REF_3V3,ADC_CH_MUXPOS_PIN3_gc); //Throttle
			gsample += adc_getsample();
			adc_init_single_ended(REF_3V3,ADC_CH_MUXPOS_PIN2_gc); //Brake
			bsample += adc_getsample();
			adc_init_differential(REF_3V3,ADC_CH_MUXPOS_PIN11_gc); //Motor current.
			isample += (int16_t)adc_getsample();
		}
	#endif

	//Convert 'em back to 12 bits.
	ad_voltage = usample/(uint32_t)ad_max_samples;
	ad_current = isample;

	//Hardware specific inputs.
	#if(HARDWARE_VER == HW_CTRL_REV1)
		ad_strain = (int32_t)ssample;
		ad_strain_sum += ad_strain;

		ad_temp = bsample/ad_max_samples;
		ad_temp_sum += ad_temp;
	#else
		ad_throttle = gsample/ad_max_samples;
		ad_brake = bsample/ad_max_samples;
	#endif

	//Summing things that need averaging.
	meas_cnt++;
	ad_voltage_sum += ad_voltage;
	ad_current_sum += ad_current;

	//Per commutation current.
	ad_current_regcnt++;
	ad_current_regsum += (ad_current/(int32_t)ad_max_samples);
}
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
int main(void){
	//Run of the internal 32MHz oscillator.
	clock_switch32M();

	init_pwm();
	uart_init();
	bus_init(&bus);

	//Clear the AD settings.
	PORTA.DIR = 0;
	PORTA.OUT = 0;
	ADCA.CTRLA  = ADC_FLUSH_bm;
	ADCA.CTRLB  = 0;
	ADCA.REFCTRL  = 0;
	ADCA.EVCTRL  = 0;
	ADCA.PRESCALER  = 0;

	//Set PORTB as AD input
	PORTB.DIR = 0;
	PORTB.OUT = 0;

	//Setup a timer, just for counting. Used for bus message and timeouts.
	TCC1_CTRLA = TC_CLKSEL_DIV1024_gc;

	//Set up the RTC for speed timing.
	CLK.RTCCTRL = CLK_RTCSRC_RCOSC32_gc | CLK_RTCEN_bm;
	RTC.CTRL = RTC_PRESCALER_DIV1_gc;
	RTC.COMP = 32768;

	//A counter for 100% PWM timing.
	TCD0.CTRLA = TC_CLKSEL_DIV1024_gc;
	TCD0.PER = 320;
	TCD0.INTCTRLA = TC_OVFINTLVL_HI_gc;


	//Make sure to move the reset vectors to application flash.
	//Set the interrupts we want to listen to.
	CCP = CCP_IOREG_gc;
	PMIC.CTRL = PMIC_LOLVLEN_bm | PMIC_MEDLVLEN_bm |PMIC_HILVLEN_bm | PMIC_RREN_bm;

	//Enable interrupts.
	sei();

	//Set defaults:
	eepsettings.straincal = 200;
	eemem_read_block(EEMEM_MAGIC_HEADER_SETTINGS,(uint8_t*)&eepsettings, sizeof(eepsettings), EEBLOCK_SETTINGS1);

	//Apply settings...
	strain_threshhold = eepsettings.straincal;
	display.function_val5 = eepsettings.straingain;
	strain_gain = eepsettings.straingain;

	//Startup hall state.
	hall_state = 0x04;
	get_hall();

	//Startup PWM value.
	pwm = PWM_SET_MIN;

	//Test
	/*
	motor.mode = 1;
	display.road_legal = false;
	display.function_val1 = 2;
	display.function_val2 = 5;
	*/
	//display.function_val1 = 2;

	uint8_t cnt_tm = 0;		//Used by TCC1
	uint8_t poll_cnt = 0;	//Used for polling the display.
	uint16_t pwm_lim = 0;	//PWM limit may change at higher speed.

	display.strain_th = strain_threshhold;

	//Two flags that can only be set.
	bool should_freewheel = true;
	bool force_commute = false;
	while(1){
		//Double check the PWM hasn't gone crazy:
		if (pwm < pwm_set_min){
			pwm = pwm_set_min;
		}
		if (pwm > pwm_set_max){
			pwm = pwm_set_max;
		}

		//Apply PWM settings.
		pwm_update();

		//Get halls sensors.
		if (!get_hall()){
			should_freewheel = true;
			status_set(STAT_HALL_FAULT);
		}

		//Commute or freewheel:
		if (should_freewheel){
			pwm_freewheel();
		}else if (force_commute){
			if (direction == FORWARD){
				commute_forward();
			}else{
				commute_backward();
			}

		}else if (flag_hall_changed){
			if (direction == FORWARD){
				commute_forward();
			}else{
				commute_backward();
			}
		}else{
			//pwm_freewheel();
		}

		//Remember...
		pwm_prev = pwm;

		//Reset
		should_freewheel = false;
		//force_commute = false;

		if (startup == 10){ //Just started
			//Setup PWM
			commute_start();
			pwm = estimate_pwm_byspeed();
			//Apply PWM settings.
			pwm_update();
		}

		if (display.online == false){
			should_freewheel = true;
		}
		if (motor.mode == 0){
			should_freewheel = true;
		}

		//Get voltage,current and whatever else.
		get_measurements();

		//Instantanious under and over voltage.
		if (ad_voltage > 3700){ //3900
			//Freewheel as fast as possible.
			pwm_freewheel();
			should_freewheel = true;
			status_set(STAT_OVER_VOLTAGE);
		}else if (ad_voltage < 1800){ //About 19 volts.
			//Freewheel as fast as possible.
			pwm_freewheel();
			should_freewheel = true;
			status_set(STAT_UNDER_VOLTAGE);
			pwm_less(200);pwm_less(200); //OMG!
		}

		//Regenning too hard:
		if (ad_current_regav < -1300){
			//Freewheel as fast as possible.
			//pwm_freewheel();
			//should_freewheel = true;
			//status_set(STAT_REGEN_HIGH);
			//startup = 3;
		}

		if (use_throttle){
			//Get the throttle value.
			if (!get_throttle()){
				status_set(STAT_THROTTLE_FAULT);
				should_freewheel = true;
			}
		}
		if (use_brake){
			//Use the brake too:
			if (get_brake()){
				if (use_brake){
					throttle_cruise = false;
					throttle_tick = 0;
				}else{
					if (throttle == 0){ //< 5
						should_freewheel = true;
					}
				}
			}else{
				status_set(STAT_BRAKE_FAULT);
				should_freewheel = true;
			}
		}

		//Maybe it'll run without at some point...
		if (usehall){
			//Timer:
			if (flag_hall_changed){
				//Toggle blue led:
				PORTC.OUTTGL = PIN7_bm;

				//compute time:
				time_now = RTC.CNT;
				time_comm = time_now;
				//Running average.
				time_comm_av += time_comm;
				time_comm_av >>= 1;

				commtime_sum+= time_comm;
				commtime_cnt++;
				cnt_commutations++;

				//Reset timer.
				RTC.CNT = 0;

				//Computer average current in this time:
				if (ad_current_regcnt > 0){
					ad_current_regav = ad_current_regsum / (int32_t)ad_current_regcnt;
				}else{
					ad_current_regav = ad_current;
				}

				//Values reset in next if-statement.
			}

			//Allowed to go faster if the commutation time is guaranteed to switch fast enough.
			if ((time_comm_av < 350)&&display.online && (display.function_val2==9)){
				#if((HARDWARE_VER==HW_BLDC_REV0)||(HARDWARE_VER==HW_BLDC_REV1))
				//TCD0 is used in case the motor suddenly stops. Capacitors are 100uF/16V
				pwm_set_min = 0;
				#else
				//PWM is inverted on this board.
				pwm_set_max = PWM_SET_MAX;
				#endif
			}

			//PWM limit for braking
			pwm_lim = pwm_set_max -  (display.function_val3 * 10);
			if (pwm_lim < pwm_set_min){
				pwm_lim = pwm_set_min;
			}else if (pwm_lim > pwm_set_max){
				pwm_lim = pwm_set_max;
			}

			//That's really slow.
			if (RTC.CNT> 5000){
				speed = 0;
			}

			//Minimum response time
			if (flag_hall_changed) {


				//Clear current sum:
				ad_current_regcnt = 0;
				ad_current_regsum = 0;

				RTC.CNT = 0;
			}

			//Control loop
			if ((flag_hall_changed) || (TCC1.CNT > 450)){
				//Clear hall flag if it was set.
				flag_hall_changed = false;
				if (!off){
					//If brake is enabled:
					if (use_brake){
						if (brake > 5){
							//Regenning is a bit harder. The amount of strength decreases if PWM is too high.
							//Brake is current limited.
							//At low speed, ovverride PWM settings
							if (speed < 150){
								pwm_lim = pwm_set_max;
							}

							if ((ad_current_regav + 169) > (((int16_t)brake)*-12)){  //100 * 10 -> current of about -8 Amp
								//More power: inc PWM

								//Use the speed average as a voltage estimate for the motor.
								//24V will give an unloaded speed of 350 (35.0kmh)
								//If we're doing 10km/h, the motor is at 7V approx, 30% duty cycle.

								if (pwm < pwm_lim){
									pwm_less(slope_brake);
								}

							}else{
								//Back off
								pwm_more(slope_brake);
							}
							//Voltage limits
							if (ad_voltage > 3600){
								pwm_more(slope_brake/2);
							}
							if (ad_voltage > 3700){
								pwm_more(slope_brake/2);
							}
						}
					}
					if (use_throttle){
						//Undo brake :
						if (flag_brake_lowrpm){
							off = false;
							tie = false;
							status_clear();
							flag_brake_lowrpm = false;
						}

						if (throttle > 5){
							//Voltage limits
							if (ad_voltage < 1950){
								pwm_less(slope_throttle*2);
							}
							if (ad_voltage < 1900){
								pwm_less(slope_throttle*2);
							}

							//Current measures this commutation cycle.
							int32_t regulation = ad_current_regav;

							//Fixed calibration. Regulation value of 100 = 1 Amp
							#if(HARDWARE_VER == HW_CTRL_REV1)
							regulation += 1749;
							regulation *= 1000;
							regulation /= 286;
							regulation -= 34;
							#else
							regulation += 169;
							regulation *= 100;
							regulation /= 75;
							regulation += 18;
							#endif

							//Target current.
							int16_t target = ((int16_t)(throttle*15)/10)*2*(int16_t)motor.mode;

							//Current regulation
							if (1){
								if (regulation < (target/4)){ //200 * 0-5
									pwm_more((speed/10)+1);
								}else if (regulation < (target/2)){
									//More power
									pwm_more(slope_throttle*2);
								}else if (regulation < target){
									//More power
									pwm_more(slope_throttle);
								}else{
									//Back off
									pwm_less(slope_throttle);
								}
							}
						}
					}

					if (use_pedalassist){
						//Compute amount of throttle 0-100% from strain signal
						pedal_signal_prev = pedal_signal;
						uint16_t pedal_new = 0;

						if (ad_strain_av > strain_threshhold){
							//Get the pedal value.
							if (ad_strain_av-strain_threshhold < 100){
								pedal_new = ad_strain_av-strain_threshhold;
								pedal_new *= strain_gain;
								if (pedal_new > 100){
									pedal_new = 100;
								}
							}else{
								pedal_new = 100;
							}

							//Reset timer.
							if (pedal_new >= pedal_signal){
								strain_cnt = 120;
							}else if (pedal_new > 20){
								strain_cnt = 60;
							}
						}

						//Take the highest as keep it there.
						if (pedal_new > pedal_signal_prev){
							pedal_signal = pedal_new;
						}
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

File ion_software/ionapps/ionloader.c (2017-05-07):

#include <stdio.h>
#include <stdint.h>


#include "../../lib/network/libdebug.h"

#include "../../lib/common/common.h"
#include "../../lib/network/uart.h"
#include "../../lib/network/stream.h"
#include "../../lib/network/message.h"
#include "../../lib/network/file.h"


#define APPDEBUG		1

#if (APPDEBUG)
 #define debprintf(a,l,...) printf_clr(a,__VA_ARGS__)
 //#define debprintf(a,l,...) printf(__VA_ARGS__)
#else
 #define debprintf(a,l,...)
#endif

//Stuff:
#define UART_BUFFER_SIZE	512
uint8_t rxbuffer[UART_BUFFER_SIZE];
uint8_t txbuffer[UART_BUFFER_SIZE];
fifo_t txfifo;
fifo_t rxfifo;
uart_s uart[1];
stream_t stream[1];

//Firmware file.
hex_file_s filefw;

//Handle all application input
#define STATE_READ 	0
#define STATE_ESC	1
#define STATE_CSI	2

#define INPUT_BUFFER_MAX	256

typedef struct termstate_s termstate_s;

struct termstate_s{
	char buffer[INPUT_BUFFER_MAX];
	int inpptr;
	char state;
};

termstate_s user_input;

//Name of the uart interface we'll use
char* ifname = "/dev/ttyS41";


#define BOOT_WAIT_REQ	0
#define BOOT_WAIT_ACK	1
#define BOOT_WRITE		2
#define BOOT_CHECK		3
#define BOOT_FINISH		4

#define BOOT_WAIT_WRITE 5

struct {
	uint8_t state;			//State we are in.
	uint8_t address;		//Address we are writing to.
	uint16_t block;			//Block we are working on.
	uint16_t offset;		//Chunk of block.
	uint16_t crc;			//CRC of current block.
	uint32_t firmwareoffs;	//Firmwareoffset.
	uint32_t size;			//Firmware total size.
	uint32_t todo;			//Firmware total size to do
	uint16_t retries;		//Amount of retries
}bootstate;

typedef struct hwinfo_t hwinfo_t;
struct hwinfo_t{
	uint16_t version;
	uint8_t boot_address;
	uint8_t dev_address;
};

typedef struct fwinfo_t fwinfo_t;
struct fwinfo_t{
	uint16_t version;
	uint16_t size;
	uint16_t crc;
};

hwinfo_t hwinfo;
fwinfo_t fwinfo;

void select_term(void);

bool app_openuart(void);
void app_get_check(uint8_t address);
void app_get_info(uint8_t address);
void app_load_firmware(uint8_t address);
void app_prepare_bootload(uint8_t start_addr);
net_error_e app_parsemessage(fifo_t* fifo);
net_error_e app_handlemessage(uint8_t* data,msg_info_t* info);

void app_init_bootstate(void){
	memset(&bootstate,0,sizeof(bootstate));
	bootstate.address = 4;
}

void app_print_info(void){
	printf("Firmware loader for OpenSource Sparta Ion Hardware. You can type the following:\n\n");

	printf("start        - Put all devices in bootload mode.\n");
	printf("startmotor   - Put only the motor in bootload mode. \n");
	printf("loadbutton   - Load button PCB. (firmware/button.hex)\n");
	printf("loadmotor    - Load motor PCB. (firmware/motor.hex)\n");
	printf("motorhex     - Only open the hexfile.\n");
	printf("info3        - Get bootinfo from button.\n");
	printf("info4        - Get bootinfo from motor.\n");

	printf("\n");
	printf("Steps for uploading motor firmware:\n");
	printf(" 1 - Make sure motor.hex is the correct file that you want to upload.\n");
	printf(" 2 - Remove power from motor.\n");
	printf(" 3 - Connect OneWire bus to PC, or whatever this is currently running on.\n");
	printf(" 4 - type 'startmotor', it will tell the motor to stay in bootload mode.\n");
	printf(" 5 - type 'loadmotor', it will upload motor.hex to the motor.\n");
	printf(" 6 - ??? \n");
	printf(" 7 - Profit\n");
	printf("\n");
	printf(" The process can be interrupted, the target device will stay in bootload mode until you complete the upload.\n");
}

void app_prepare_bootload(uint8_t start_addr){
	net_error_e err;
	//Temp location for data:
	uint8_t msgdata[128];
	msg_info_t info;

	//Send a boot info:
	bootstate.address = start_addr;

	bool resp_button = false;
	if (start_addr == 4){
		resp_button = true;
	}

	bool resp_motor = false;

	while(1){
		//Read an arbitrary number of bytes
		int n = uart_read_start(uart,60);


		//Message?
		bool message_found = false;
		while (messages_infifo(&rxfifo)){
			message_found = true;
			//We expect the same back:
			err = parse_message(uart->rxfifo,msgdata,128,&info);
			if (err != NET_ERR_NONE){
				debprintf(CLR_YELLOW,0,"Invalid message\n");
				usleep(20000);
			}else{
				//What should we do with the message?

				bool ack = ((info.cmd & MASK_CMD_ACK) == MASK_CMD_ACK);
				uint8_t cmd = info.cmd & MASK_CMD;
				//Went ok.
				debprintf(CLR_GREEN,0,"Parse OK: addr %u cmd: %02X ACK: %u\n",info.address,cmd,ack);

				if ((cmd == CMD_BOOT_INFO) && ack){

					if (info.address == 3){
						bootstate.address = 4;
						debprintf(CLR_CYAN,0,"ACK from BUTTON.\n");
						resp_button = true;
					}else if (info.address == 4){
						bootstate.address = 3;
						debprintf(CLR_CYAN,0,"ACK from MOTOR.\n");
						resp_motor = true;
					}
				}
			}
		}

		if (!message_found){
			printf_clr(CLR_YELLOW,"No message.\n");
			if (fifo_free(&rxfifo) == 0){
				fifo_clear(&rxfifo);
				printf("Cleared fifo\n");
			}
		}

		debprintf(CLR_CYAN,0,"\nSending message to %i\n",bootstate.address);
		message_append_tofifo(uart->txfifo,NULL,0,CMD_BOOT_INFO,bootstate.address);
		uart_write_start(uart);

		if (resp_motor && resp_button){
			debprintf(CLR_GREEN,0,"\nBoth devices are in bootload state.\n");
			return;
		}
		select_term();
	}
}
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

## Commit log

2015-04-05 Added farnell parts to eagledb file, BOM.
    [3phasecntrl-rev0.brd, 3phasecntrl-rev0.sch, partsdb.tsv]
2015-04-06 Current regulation in steps of ~3 Amps. Strain calibration faster by holding it down, single button presses. Some typos fixed.
    [bldcdisp.c, bowbus.c]
2015-04-08 PWM naming is intuitive: less is less, more is more. Strain signal is held at highest for a period. Implemented some FW_ features from app.h Roadlegal will now allow throttle override from middle but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
    [ftdi.brd, ftdi.sch]
2015-04-12 Strain sensor with signed ad value, highest gain. Averaging moved, produced aliasing issues. Bootloader dind;t want to stay in bootload mode. Removed hex files from commit. Bom added
    [3phasecntrl-rev1.sch, ftdi.brd, ftdi.sch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]
2015-04-12 Manual and connector partlist.
2017-05-07 Added retries on firmware load. Removed throttle by default.
2017-05-07 Rev. 2 board: Added throttle input, added 3 TVS on hall sensor
    [3phasecntrl-rev2.brd, 3phasecntrl-rev2.sch]
2017-05-07 Hall state in function1.6 PWM update uses buffer.
2017-05-09 Updated readme. Updated REV2 silkscreen.
    [3phasecntrl-rev2.brd]

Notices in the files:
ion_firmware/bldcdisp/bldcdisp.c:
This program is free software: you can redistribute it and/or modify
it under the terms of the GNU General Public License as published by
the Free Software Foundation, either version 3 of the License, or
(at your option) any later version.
